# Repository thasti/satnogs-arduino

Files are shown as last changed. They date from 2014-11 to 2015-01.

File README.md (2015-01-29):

SatNOGS Arduino
===============

Repository of Arduino code and Arduino PCB for SatNOGS project.
Refer to block diagram in the repository for wiring documentation.

Electronics and code are modified to work with a bare AtMega328p with the Arduino Bootloader. This spares buying the Arduino Micro. The stepper motor drivers are replaced by DRV8825 modules (Drop-in replacement part) from eBay.

This will be used in our costumized version of the SatNOGS PCB for the High Altitude Object Tracker, which will be part of the SatNOGS project as well.

# Flashing Instructions

Use the following command line to ISP the AtMega328p from an AVR910

avrdude -cavr910 -b115200 -P/dev/ttyUSB1 -pm328p -U lfuse:w:0xFF:m -U hfuse:w:0xDE:m -U efuse:w:0x05:m -v -x devcode=0x31

avrdude -pm328p -b115200 -cavr910 -x devcode=0x31 -P/dev/ttyUSB0 -U flash:w:SatNOGS.hex -v

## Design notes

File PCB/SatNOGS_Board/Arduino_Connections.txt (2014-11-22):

#	Function	SatNOGS needed	optional	AtMega32U4	AtMega48
D1	TX		-				PD3		PD1
D0	RX		-				PD2		PD0
GND	-		GND
GND	-		GND
D2	SDA				SDA (optional)	PD1		PD2
D3	PWM/SCL				SCL (optional)	PD0		PD3
D4	A6		Homing 1 (SW1)			PD4		PD4
D5	PWM		Homing 2 (SW2)			PD5		PD5
D6	PWM		DIR2				PC6		PD6
D7	-		STEP2				PE6		PD7
D8	A8		M_EN				PB4		PB0
D9	PWM/A9		MODE1				PB5		PB1
D10	PWM/A10		STEP1				PB6		PB2
D16	MOSI				IO (optional)	PB2		-
D14	MISO				IO (optional)	PB3		-
D15	SCLK				IO (optional)	PB1		-
D18	A0		DIR1				PF7		PC0 (A0, nicht D18)
D19	A1				IO (optional)	PF6		PC1
D20	A2				IO (optional)	PF5		PC2
D21	A3				IO (optional)	PF4		PC3
VCC	-		VCC
RST	-		RST
GND	-		GND
RAW	-				to VMOTOR 	(5V)

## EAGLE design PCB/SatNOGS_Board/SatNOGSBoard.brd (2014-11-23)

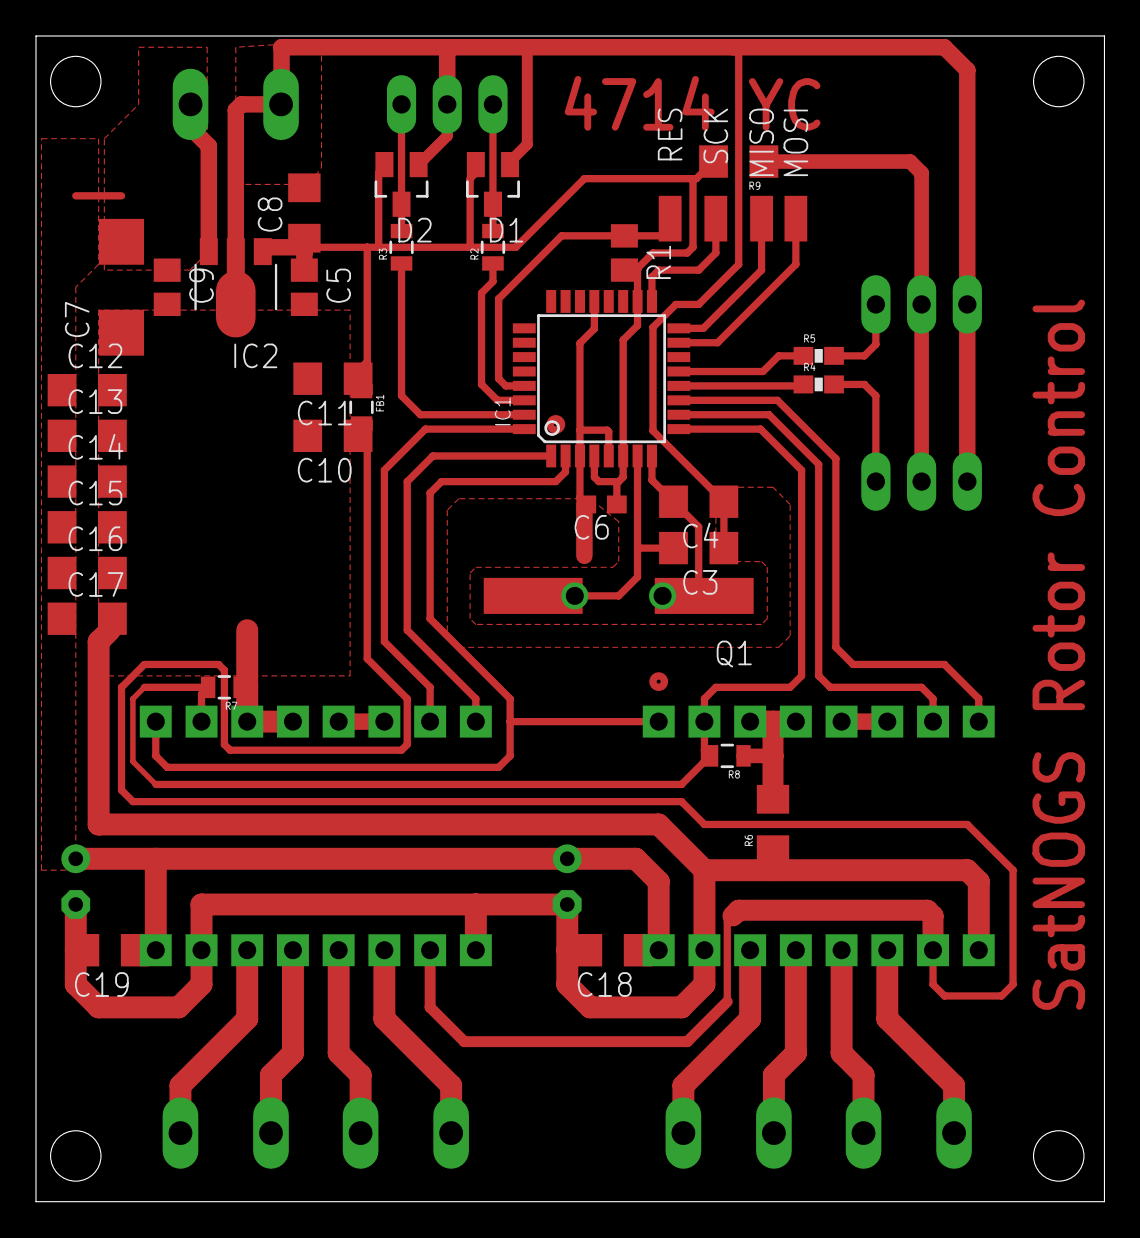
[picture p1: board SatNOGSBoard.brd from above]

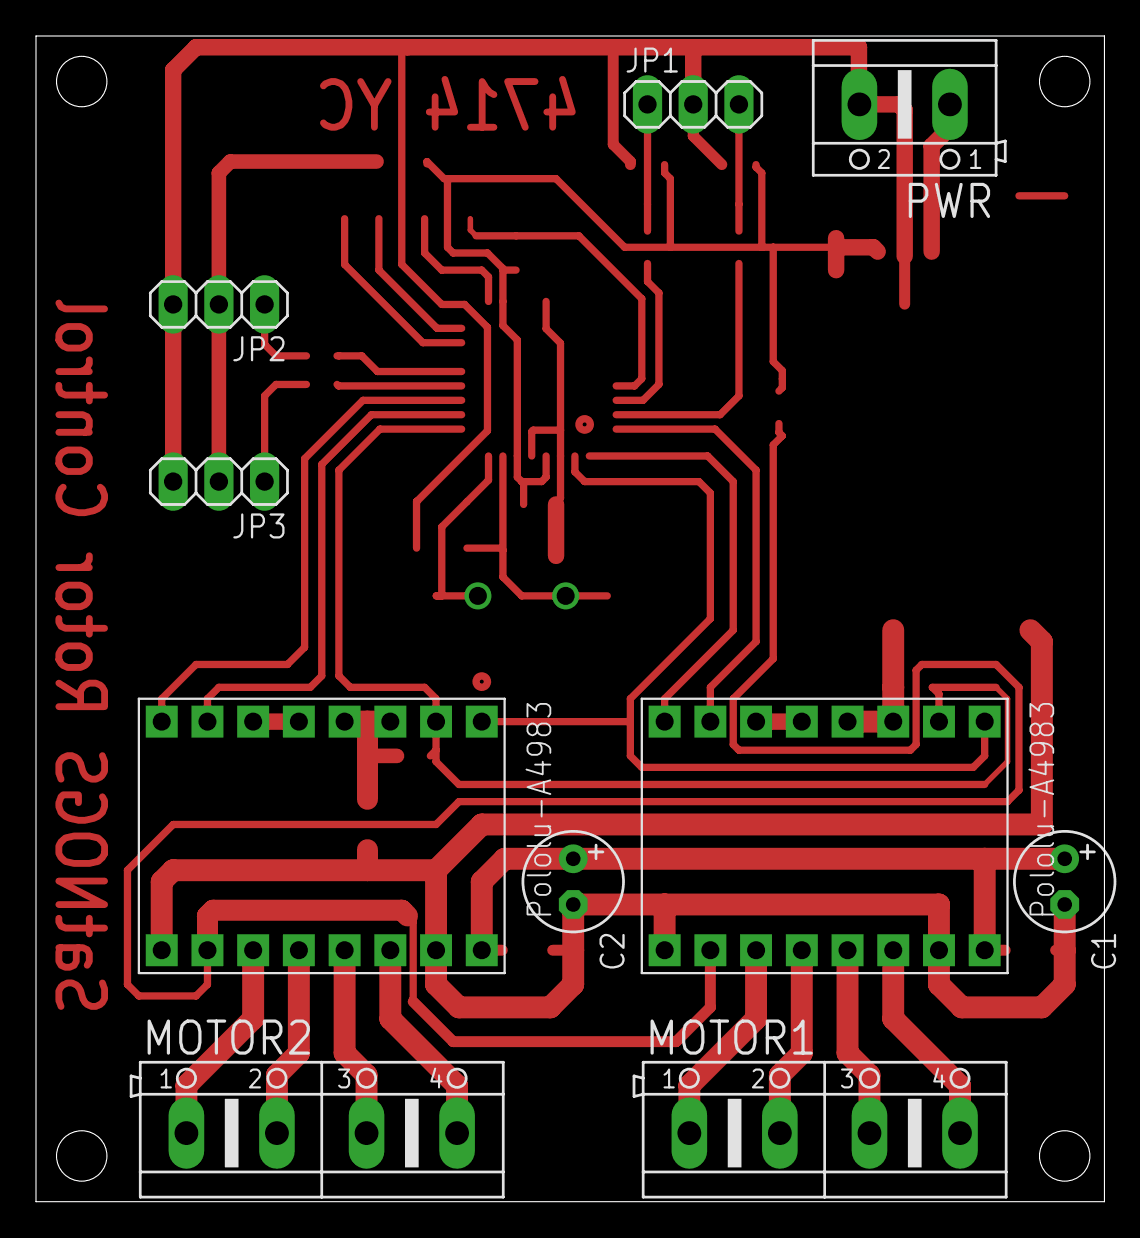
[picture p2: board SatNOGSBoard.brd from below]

Board: 2 copper layers, 59.4 x 64.8 mm, 46 parts (10 on the bottom side), 36 nets.

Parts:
C1, C2: 100uF; E2,5-6
C3, C4: 18p; C1206
C5, C9: 100n; C0805
C6: 100n; C0603
C7: C/6032-28R
C8, C10, C11, C12, C13, C14, C15, C16, C17, C18, C19: 680n; C1206
D1, D2: BAV99; SOT23
DRIVER1, DRIVER2: POLOLU-A4983POLOLU-A4983; POLOLU-A4983
FB1: 10R@100MHz; 0805
IC1: MEGA8-AI; TQFP32-08
IC2: 78L05F; SOT89
JP1, JP2, JP3: 1X03
MISO: SMD1,27-2,54
MOSI: SMD1,27-2,54
MOTOR1: 2; AK500/4
MOTOR2: 3; AK500/4
PWR: 1; AK500/2
Q1: 16MHz; CSM-7X-DU
R1: 4k7; R0805
R2: 1k; 0805
R3: 475R; 0805
R4, R5: 0603-RES
R6, R9: 0R; 1206
R7, R8: 100k; 0805
RES: SMD1,27-2,54
SCK: SMD1,27-2,54

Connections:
1-1A: DRIVER1.12, MOTOR1.2
1-1B: DRIVER1.11, MOTOR1.1
1-2A: DRIVER1.13, MOTOR1.3
1-2B: DRIVER1.14, MOTOR1.4
2-1A: DRIVER2.12, MOTOR2.2
2-1B: DRIVER2.11, MOTOR2.1
2-2A: DRIVER2.13, MOTOR2.3
2-2B: DRIVER2.14, MOTOR2.4
+5V: C5.1, C6.1, C8.1, C11.1, D1.2, D2.2, FB1.1, IC1.4, IC1.6, IC1.18, IC2.1, R1.2, R9.2
+5VM: C10.1, DRIVER1.10, DRIVER2.10, FB1.2
+12V: C1.+, C2.+, C7.+, C9.1, C12.1, C13.1, C14.1, C15.1, C16.1, C17.1, C18.1, C19.1, DRIVER1.16, DRIVER2.16, IC2.3, PWR.1
DIR-1: DRIVER1.8, IC1.1
DIR-2: DRIVER2.8, IC1.11
GND: C1.-, C2.-, C3.1, C4.1, C5.2, C6.2, C7.-, C8.2, C9.2, C10.2, C11.2, C12.2, C13.2, C14.2, C15.2, C16.2, C17.2, C18.2, C19.2, D1.1, D2.1, DRIVER1.3, DRIVER1.4, DRIVER1.9, DRIVER1.15, DRIVER2.9, DRIVER2.15, IC1.3, IC1.5, IC1.21, IC2.2, IC2.2@1, JP1.2, JP2.3, JP3.3, PWR.2, R6.1, R7.1
MS1: DRIVER1.2, DRIVER2.2, IC1.9, R7.2, R8.2
M_EN: DRIVER1.1, DRIVER2.1, IC1.2
unnamed: DRIVER1.5, DRIVER1.6
unnamed: DRIVER2.5, DRIVER2.6
unnamed: D1.3, JP1.1, R2.2
unnamed: D2.3, JP1.3, R3.2
unnamed: IC1.29, R1.1, RES.1
unnamed: IC1.30, R2.1
unnamed: IC1.31, R3.1
unnamed: IC1.13, R5.1
unnamed: IC1.15, MOSI.1
unnamed: IC1.16, MISO.1
unnamed: IC1.17, SCK.1
unnamed: IC1.12, R4.1
unnamed: DRIVER2.3, DRIVER2.4, R6.2, R8.1
unnamed: JP2.2, JP3.2, R9.1
STEP-1: DRIVER1.7, IC1.32
STEP-2: DRIVER2.7, IC1.10
SW1: JP2.1, R5.2
SW2: JP3.1, R4.2
XTAL1: C3.2, IC1.7, Q1.2
XTAL2: C4.2, IC1.8, Q1.1

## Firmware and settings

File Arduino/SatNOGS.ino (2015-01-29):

#include <string.h>
#include <stdlib.h>
#include <math.h>
#include <AccelStepper.h>

#define DIR_AZ 3 //PIN for Azimuth Direction
#define STEP_AZ 2 //PIN for Azimuth Steps
#define DIR_EL 7 //PIN for Elevation Direction
#define STEP_EL 6 //PIN for Elevation Steps

#define MS1 5 //PIN for step size
#define EN 4 //PIN for Enable or Disable Stepper Motors

#define SPR 200 //Step Per Revolution
#define RATIO 60 //Gear ratio
#define T_DELAY 60000 //Time to disable the motors in millisecond

#define HOME_AZ 9 //Homing switch for Azimuth
#define HOME_EL 8 //Homing switch for Elevation
/*The MAX_ANGLE depends of ANGLE_SCANNING_MULT and maybe misbehave for large values*/
#define ANGLE_SCANNING_MULT 180 //Angle scanning multiplier
#define MAX_AZ_ANGLE 360 //Maximum Angle of Azimuth for homing scanning
#define MAX_EL_ANGLE 360 //Maximum Angle of Elevation for homing scanning

#define HOME_DELAY 6000 //Time for homing Decceleration in millisecond

/*Global Variables*/
unsigned long t_DIS = 0; //time to disable the Motors
/*Define a stepper and the pins it will use*/
AccelStepper AZstepper(1, STEP_AZ, DIR_AZ);
AccelStepper ELstepper(1, STEP_EL, DIR_EL);

void setup()
{  
  /*Change these to suit your stepper if you want*/
  AZstepper.setMaxSpeed(200);
  AZstepper.setAcceleration(200);
  
  /*Change these to suit your stepper if you want*/
  ELstepper.setMaxSpeed(400);
  ELstepper.setAcceleration(200);
  
  /*Enable Motors*/
  pinMode(EN, OUTPUT);
  digitalWrite(EN, LOW);
  /*Step size*/
  pinMode(MS1, OUTPUT);
  digitalWrite(MS1, LOW); //Full step
  /*Homing switch*/
  pinMode(HOME_AZ, INPUT);
  pinMode(HOME_EL, INPUT);
  /*Serial Communication*/
  Serial.begin(19200);
  /*Initial Homing*/
  Homing(deg2step(-ANGLE_SCANNING_MULT), deg2step(-ANGLE_SCANNING_MULT));
}

void loop()
{ 
  /*Define the steps*/
  static int AZstep = 0;
  static int ELstep = 0;
  
  /*Time Check*/
  if (t_DIS == 0)
    t_DIS = millis();

  /*Disable Motors*/
  if (AZstep == AZstepper.currentPosition() && ELstep == ELstepper.currentPosition() && millis()-t_DIS > T_DELAY)
  {
    digitalWrite(EN, HIGH);
  }
  /*Enable Motors*/
  else
    digitalWrite(EN, LOW);
    
  /*Read the steps from serial*/
  cmd_proc(AZstep, ELstep);
  /*Move the Azimuth & Elevation Motor*/
  stepper_move(AZstep, ELstep);
}

/*Homing Function*/
void Homing(int AZsteps, int ELsteps)
{
  int value_Home_AZ = HIGH;
  int value_Home_EL = HIGH;
  int n_AZ = 1; //Times that AZ angle has changed
  int n_EL = 1; //Times that EL angle has changed
  boolean isHome_AZ = false;
  boolean isHome_EL = false;
  
  AZstepper.moveTo(AZsteps);
  ELstepper.moveTo(ELsteps);
  
  while(isHome_AZ == false || isHome_EL == false)
  {
    value_Home_AZ = digitalRead(HOME_AZ);
    value_Home_EL = digitalRead(HOME_EL);

    if (value_Home_AZ == LOW)
    {
      AZstepper.moveTo(AZstepper.currentPosition());
      isHome_AZ = true;
    }   
    if (value_Home_EL == LOW)
    {
      ELstepper.moveTo(ELstepper.currentPosition());
      isHome_EL = true;
    }
    if (AZstepper.distanceToGo() == 0 && !isHome_AZ)
    {
      n_AZ++;
      AZsteps = deg2step(pow(-1,n_AZ)*n_AZ*ANGLE_SCANNING_MULT);
      if (abs(n_AZ*ANGLE_SCANNING_MULT) > MAX_AZ_ANGLE)
      {
        error(0);
        break;
      }
      AZstepper.moveTo(AZsteps);
    } 
    if (ELstepper.distanceToGo() == 0 && !isHome_EL)
    { 
      n_EL++;
      ELsteps = deg2step(pow(-1,n_EL)*n_EL*ANGLE_SCANNING_MULT);
      if (abs(n_EL*ANGLE_SCANNING_MULT) > MAX_EL_ANGLE)
      {
        error(1);
        break;
      }
      ELstepper.moveTo(ELsteps);
    }
    
    AZstepper.run();
    ELstepper.run();
  }
  /*Delay to Deccelerate*/
  long time = millis();  
  while(millis() - time < HOME_DELAY)
  {  
    AZstepper.run();
    ELstepper.run();
  }
  /*Reset the steps*/
  AZstepper.setCurrentPosition(0);
  ELstepper.setCurrentPosition(0); 
}
 
/*EasyComm 2 Protocol & Calculate the steps*/
void cmd_proc(int &stepAz, int &stepEl)
{
  /*Serial*/
  char buffer[256];
  char incomingByte;
  char *p=buffer;
  char *str;
  int counter=0;
  char data[100];
  
  double angleAz,angleEl;
  
  /*Read from serial*/
  while (Serial.available() > 0)
  {
    incomingByte = Serial.read();
    /* XXX: Get position using custom and test code */
    if (incomingByte == '!')
    {
      /* Get position */
      Serial.print("TM");
      Serial.print(1);
      Serial.print(" ");
      Serial.print("AZ");
      Serial.print(10*step2deg(AZstepper.currentPosition()), 1);
      Serial.print(" ");
      Serial.print("EL");
      Serial.println(10*step2deg(ELstepper.currentPosition()), 1);
    }
    /*new data*/
    else if (incomingByte == '\n')
    {
      p = buffer;
      buffer[counter] = 0;
      if (buffer[0] == 'A' && buffer[1] == 'Z')
      {
        if (buffer[2] == ' ' && buffer[3] == 'E' && buffer[4] == 'L')
        {
          /* Get position */
          Serial.print("AZ");
          Serial.print(step2deg(AZstepper.currentPosition()), 1);
          Serial.print(" ");
          Serial.print("EL");
          Serial.print(step2deg(ELstepper.currentPosition()), 1);
          Serial.println(" ");
        }
        else
        {
          /*Get the absolute value of angle*/
          str = strtok_r(p, " " , &p);
          strncpy(data, str+2, 10);
          angleAz = atof(data);
          /*Calculate the steps*/
          stepAz = deg2step(angleAz);

          /*Get the absolute value of angle*/
          str = strtok_r(p, " " , &p);
          if (str[0] == 'E' && str[1] == 'L')
          {
            strncpy(data, str+2, 10);
            angleEl = atof(data);
            /*Calculate the steps*/
            stepEl = deg2step(angleEl);
          }
        }
      }
      /* Stop Moving */
      else if (buffer[0] == 'S' && buffer[1] == 'A' && buffer[2] == ' ' && buffer[3] == 'S' && buffer[4] == 'E')
      {
        /* Get position */
        Serial.print("AZ");
        Serial.print(step2deg(AZstepper.currentPosition()), 1);
        Serial.print(" ");
        Serial.print("EL");
        Serial.println(step2deg(ELstepper.currentPosition()), 1);
        stepAz = AZstepper.currentPosition();
        stepEl = ELstepper.currentPosition();
      }
      /* Reset the rotator */
      else if (buffer[0] == 'R' && buffer[1] == 'E' && buffer[2] == 'S' && buffer[3] == 'E' && buffer[4] == 'T')
      {
        /* Get position */
        Serial.print("AZ");
        Serial.print(step2deg(AZstepper.currentPosition()), 1);
        Serial.print(" ");
        Serial.print("EL");
        Serial.println(step2deg(ELstepper.currentPosition()), 1);
        /*Move the steppers to initial position*/
        Homing(0,0);
        /*Zero the steps*/
        stepAz = 0;
        stepEl = 0;
      }      
      counter = 0;
      /*Reset the disable motor time*/
      t_DIS = 0;
    }
    /*Fill the buffer with incoming data*/
    else {
      buffer[counter] = incomingByte;
      counter++;
    }
  }
}

/*Error Handling*/
void error(int num_error)
{
  switch (num_error)
  {
    /*Azimuth error*/
    case (0):
      while(1)
      {
        Serial.println("AL001");
        delay(100);
      }
    /*Elevation error*/
    case (1):
      while(1)
      {
        Serial.println("AL002");
        delay(100);
      }
    default:
      while(1)
      {
        Serial.println("AL000");
        delay(100);
      }
  }
}

/*Send pulses to stepper motor drivers*/
void stepper_move(int stepAz, int stepEl)
{
  AZstepper.moveTo(stepAz);
  ELstepper.moveTo(stepEl);
    
  AZstepper.run();
  ELstepper.run();
}

/*Convert degrees to steps*/
int deg2step(double deg)
{
  return(RATIO*SPR*deg/360);
}

/*Convert steps to degrees*/
double step2deg(int Step)
{
  return(360.00*Step/(SPR*RATIO));
}

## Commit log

2014-09-28 Add arduino code with homing function.
2014-10-07 Add homing function.
2014-10-08 Add homing function and homing command extension for easyCom 2.
2014-11-22 add arduino pro micro pinout
2014-11-22 add AtMega48 Pin Mapping
2014-11-23 update pin assignments in Arduino code
    I don't know yet, wheter that change of pins will work.
2014-11-23 schematic update, raw routing prototype
    this adds the AtMega168 and neccesary components. Layout is just a raw
    sketch, someone should finish that.
    [SatNOGSBoard.brd, SatNOGSBoard.sch]
2014-11-23 board routing
    [SatNOGSBoard.brd, SatNOGSBoard.sch]
2014-11-23 correct pinout in Arduino code
    [SatNOGS.ino]

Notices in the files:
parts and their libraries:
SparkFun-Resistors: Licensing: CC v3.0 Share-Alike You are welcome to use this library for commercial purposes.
